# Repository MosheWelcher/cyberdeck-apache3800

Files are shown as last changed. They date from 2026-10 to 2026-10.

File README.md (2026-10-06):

# Apache 3800 Cyberdeck — panels CAD

Parametric OpenSCAD panels for a cyberdeck built into a Harbor Freight
**Apache 3800** case (item 63927).

- **Lid:** screen panel + screen clips + lid brackets (this repo).
- **Base:** keyboard / ports faceplate that screws onto the
  [Apache 3800 Panel Bracket](https://www.printables.com/model/1478000-apache-3800-panel-bracket)
  by JohnS - N0CTL (print that ring separately; its hole pattern is built in here).

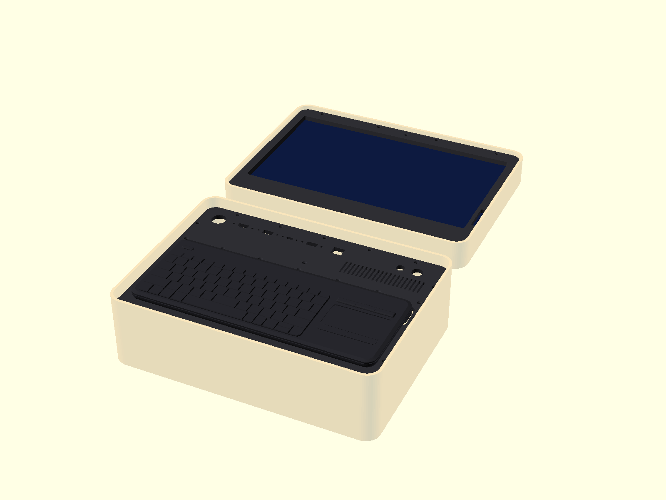
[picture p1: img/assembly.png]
assembly


## Layout

| File | What it is |
|---|---|
| `config.scad` | **Every dimension lives here.** Case, screen preset, ports, keyboard, printer bed, fasteners. |
| `parts/lid_panel.scad` | Screen bezel: window with 45° bevel, retainer bosses on the back, countersunk mount holes. |
| `parts/screen_retainer.scad` | Flat clips that screw onto the bosses and clamp the screen. |
| `parts/lid_bracket.scad` | Posts for the lid floor (insert top + bottom) — lid-side equivalent of the Printables bracket. |
| `parts/base_faceplate.scad` | Keyboard battery-hump slot, port cutouts, vent grille, holes matching the Printables bracket ring. |
| `view_stls.scad` | Imports the exported STLs so you can look at them (F5). |
| `assembly.scad` | Fit-check: case opened flat with both panels. Preview only. |
| `scripts/export.sh` | Renders every part to `stl/` and previews to `img/`. |
| `scripts/step_to_stl.py` | Converts a STEP to STL (gmsh) for previews, e.g. the K400 model. |
| `scripts/step_info.py` | Reads holes / extents / faces out of STEP files (how third-party parts were measured). |
| `docs/DESIGN.md` | Design record: every decision, measurement source, open question. |
| `CLAUDE.md` / `AGENTS.md` | Guide for AI agents (and humans) working on the repo. |
| `ref/` | Notes on reference dimensions. |

Coordinates: origin at the centre of the case opening; **−Y = handle (front)**,
**+Y = hinge (back)**; panel front face is the top (+Z).

## Workflow

1. Edit `config.scad` (screen preset, port list, keyboard size, `bed`).
2. Open `assembly.scad` in OpenSCAD, press **F5** to fit-check.
3. Export STLs from Git Bash in the repo root:
   ```bash
   scripts/export.sh
   ```
   ~10 s with an OpenSCAD **development build** (2024+, Manifold engine); the
   script finds one under `%LOCALAPPDATA%\Programs\OpenSCAD-Nightly` and falls
   back to the 2021.01 release (~35 min). Get builds from
   openscad.org → Downloads → Development Snapshots. Single part:
   `openscad --backend=manifold -D 'piece=[0,1]' -o out.stl parts/lid_panel.scad`.

## Splitting for the printer

The panels are ~380 × 270 mm. If they exceed `bed` (default 256 × 256) they are
cut into tiles with a **half-lap joint**: the back half of one tile overlaps the
front half of its neighbour across a `lap_w` band. Each seam gets M3 countersunk
screws (front) + hex-nut pockets (back) every `seam_hole_pitch` mm — glue the lap
too. Force a layout with e.g. `lid_split_x = [0]; lid_split_y = [];`, or set
both to `[]` for a single piece on a big bed. Tiles export as
`<part>_tile_<i>_<j>.stl`.

## What's measured vs. assumed

**From the Printables bracket STEP (v8):**
- Case interior at bracket height: **380 × 270 mm, R17 corners.**
- 16 M3 insert positions of the 4-piece bracket ring → `base_mount_holes`.
- Bracket height 17 mm.

**From Harbor Freight spec:** inside 383 × 271 mm at the rim, lid depth 44 mm,
base depth 108 mm.

**MEASURE before printing** (tagged in `config.scad`):
- `lid_panel_drop` — how far below the lid rim the screen panel sits (gasket lip).
- `base_panel_drop` — where your brackets end up below the base rim (16 mm default so the lid clears the keyboard).
- Screen preset dimensions — all approximate; caliper your panel + driver board.
- Port type sizes — generic panel-mount extensions vary.

## Screen: portable "travel" monitor

Default `screen = "vilva15.6"`: the **VILVA V156F1** 15.6" FHD monitor
([Amazon B0BTSFVMLV](https://www.amazon.com/dp/B0BTSFVMLV)), 367.8 × 224.8 ×
7.6 mm from the listing — not yet measured. Its ports and buttons are split
over both short ends, with only ~5.5 mm to the lid wall (checked against the
case CAD): use very low-profile right-angle plugs that turn toward the lid
floor. A finger notch in the panel's right end (`lid_notches` in
`config.scad`) lets you reach the power button and brightness wheel — check
which end yours are on and move it if needed. Generic presets `"travel15.6"` / `"travel14"` remain.
`lid_panel.scad` stops with an error if a monitor is too big for the clip /
lid-post layout. A travel monitor is a whole
unit in its own ~9 mm shell, so the panel frames its glass and the clips clamp
the shell edge — no teardown needed. To fit yours, measure and edit its preset:

- outer shell width × height × thickness (`module_w/h/t`)
- visible picture area width × height (`active_w/h`)
- picture-centre offset: travel monitors have a thicker bottom chin, so the
  picture sits **higher** than the shell centre (`active_off_y`, ~+5–10 mm)

Things to plan for: its USB-C / mini-HDMI ports and OSD buttons are on the shell
edges, which end up behind the panel — check that the cable plugs (often
right-angle ones are needed) clear the lid brackets, and set brightness before
mounting.

## Keyboard: Logitech K400 Plus (sits on top)

The K400 sits **flat on top of the faceplate**. Only its battery hump (the
thicker strip along its back edge, ~8 mm deeper than the flat underside)
drops through a **357 × 40.5 mm slot with R6 rounded corners** in the plate
(sized from the real K400 model + 1 mm clearance). The hump in the slot also
locates the keyboard so it can't slide; add a few velcro dots if you want it
held down. Lift it off to use it wirelessly or change batteries.

- The slot sits under the keyboard's back edge (keyboard centred at
  `kb_offset`, hump toward the hinge). 14 of the 16 bracket holes are used — the middle
  hole on each end bracket sits too close to the slot end and is skipped.
- With the keyboard on top it stands ~14 mm above the plate, so the plate is
  set **16 mm below the base rim** (`base_panel_drop`) — that leaves ~8 mm
  between the keys and the lid panel when the case is closed. Mount the
  brackets at that height (or change the value and re-export).
- **See it on the plate:** `assembly.scad` and `view_stls.scad` show the real
  K400 model when `ref/local/k400_plus.stl` exists (kept out of the repo —
  GrabCAD terms). Make it once from the GrabCAD STEP (needs
  `pip install --user gmsh`):
  `python scripts/step_to_stl.py <Downloads>/Logitech_K400_PLUS.stp ref/local/k400_plus.stl`.
  Without it, set `kb_model_stl = ""` in config.scad to see a box stand-in.
- The horizontal print seam sits behind the keyboard (`base_split_y = [44]`);
  ports and vent are in the strip behind it.

Details: `ref/k400-plus.md`.

## License

[MIT](LICENSE) © MosheWelcher — except third-party files in `ref/`, which keep
their own licenses (listed in [`NOTICE`](NOTICE) and below).

## Credits

- **Apache 3800 Panel Bracket** by JohnS - N0CTL —
  [Printables 1478000](https://www.printables.com/model/1478000-apache-3800-panel-bracket),
  [CC BY 4.0](https://creativecommons.org/licenses/by/4.0/). Original STEP included
  unmodified in `ref/`; `base_mount_holes` and the case interior/corner dimensions
  are derived from it. See `ref/printables-bracket.md`.
- **Logitech K400 Plus** model by Tomáš Stroka —
  [GrabCAD](https://grabcad.com/library/logitech-k400-plus-2); keyboard
  outline and underside profile measured from it (file not redistributed).

## Hardware

- Battery charge port: [Adafruit 4218](https://www.adafruit.com/product/4218) USB-C round panel mount (22 mm hole, port row)
- M3 heat-set inserts (M3 × 5.7, 4.0 mm hole)
- M3 countersunk screws: 10 mm (6 mm panels), M3 hex nuts (seams)
- Foam tape for `screen_shim`
- Print: PETG / ABS / ASA-GF, 4 walls, 4 top/bottom, 30–45 % infill.
  Print panels front-face-down for a clean visible side.

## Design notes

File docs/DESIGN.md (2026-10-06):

# Design record — Apache 3800 cyberdeck panels

Everything an agent or collaborator needs to continue the design: what was
decided, why, where every number came from, what is still open. Keep it
current — append to the decision log when you change something.

Coordinates: mm, origin at the centre of the case opening, **−Y = front
(handle)**, **+Y = hinge**, +X = right. Numbers below are for the current
`config.scad` defaults.

---

## 1. Hardware (decided by the owner)

| Item | Choice | Status |
|---|---|---|
| Case | Harbor Freight **Apache 3800** (item 63927) | owned |
| Screen | **VILVA V156F1** 15.6" FHD portable monitor ([amazon.com/dp/B0BTSFVMLV](https://www.amazon.com/dp/B0BTSFVMLV)), USB-C + mini-HDMI | model known (2026-10-05); preset `vilva15.6` from the listing — **not measured yet** |
| Keyboard | **Logitech K400 Plus** (keyboard + touchpad, wireless, 2×AA) | decided; modelled from a STEP |
| Base mounting | **Printables 1478000 "Apache 3800 Panel Bracket"** (4-piece ring, M3 heat-set inserts) | owner has the STEP + a Bambu `.3mf` for it |
| Printer | **Bambu X1C**, 256 × 256 bed | → panels split into 2 × 2 tiles |
| Computer / battery / I/O boards | **not chosen** | don't assume; ask |

## 2. Case

Harbor Freight spec: inside 383 × 271 mm at the rim (15.063" × 10.688"), lid
depth 44 mm (1.75"), base depth 108 mm (4.25"). Front = handle side, hinge at
the back.

**Source ranking (owner, 2026-10-06):** 1. the Printables bracket STEP
(photos show it fitted in real cases) → **380 × 270 mm, R17 corners**
(fillet centres ±173, ±118), used for both halves; 2. the Harbor Freight spec
→ lid depth **44**; 3. a third-party case CAD from the web (`Lid.step`, see
`ref/apache-3800-case.md`, low trust) → only what 1 and 2 don't cover, tagged
`MEASURE`: walls lean in **0.03 mm per mm**, **≈R21 rounded corner** where the
lid walls meet the floor (starts ~28 mm down; 16 mm wide at the floor),
gasket groove in the top of the wall with nothing sticking into the cavity.
It disagrees with 1/2 on corner radius (R20) and lid depth (46.5).

Unmeasured (tagged `MEASURE`): `lid_panel_drop` (how far below the lid rim the
screen panel face sits; the CAD shows no gasket lip inside, so 6 is a free
choice), `base_panel_drop` (where the brackets end up below the base rim).

## 3. Lid — screen panel

Files: `parts/lid_panel.scad`, `parts/screen_retainer.scad`, `parts/lid_bracket.scad`.

- **Panel**: 377.3 × 267.3 mm, R15.6, 6 mm thick (`case_in − 2·(panel_gap +
  lid_draft_inset)`; the draft inset is the wall lean at the panel's back face).
- **Monitor**: VILVA V156F1 (`vilva15.6`). Listing: 14.48 × 8.85 × 0.30" →
  **367.8 × 224.8 × 7.6 mm** (photos say 0.19" = 4.8 mm at the thin edge, so
  7.6 is the thickest point), 1.68–1.88 lb, 1920 × 1080 IPS → standard 15.6"
  active area 344.2 × 193.6. Thin top/side bezels, thick bottom chin: picture
  centre estimated **+10 mm** above the shell centre from product photos.
  **Controls are on both short edges** (manual's "Function Keys & Ports"
  diagram): one edge has mini-HDMI + 2 × USB-C; the other has the 3.5 mm
  jack, OTG USB, the **multi-function wheel** (push up = brightness, press =
  menu), a power LED and the **power button**. Both groups sit in the thick
  chin end; rough diagram reading: wheel ≈ 49 mm, power ≈ 68 mm from the
  bottom edge. Which edge is left/right is not confirmed. (Earlier notes said
  "all on the right" — wrong.)
- **Window**: active area + 0.5 mm/side = **345.2 × 194.6 mm**, centred at
  (0, +10). 45° × 2 mm bevel on the viewing side.
- **Monitor retention**: 8 bosses on the panel back, **all on the long edges**
  (4 per edge at x = ±46, ±137.9, y = ±116.9), height = monitor thickness +
  0.5 mm foam shim, M3 heat-set insert each. 8 flat clips (`screen_retainer`)
  screw on and overlap the monitor shell by 4 mm. No short-edge bosses: the
  368 mm shell leaves only ~4.7 mm per side inside the 377 mm panel. Even count
  keeps x = 0 free for the seam. If the shell is wedge-shaped (4.8 → 7.6 mm),
  the thin-edge clips need extra foam.
- **Mounting**: 8 countersunk M3 holes (`lid_mount_holes`, y = ±127.9) — 4
  per long wall at x = ±50, ±150 — onto **8 printed posts** (`lid_post()` in
  `lib/common.scad`, exported as `lid_bracket`): 18 × 12 × **32 mm** (lid
  depth − drop − panel). The posts **sit on the floor fillet** (their bottom is
  cut to the R21 curve with a 0.3 mm glue gap) with the back face 0.3 mm off
  the wall — they cannot reach the flat floor, the fillet fills the bottom
  16 mm next to the wall. Sized for the 44 mm spec depth: if the lid is
  really 46.5 deep (case CAD), they hang up to 2.5 mm above the fillet and
  the wall screw / glue holds them — so they fit either way. Inserts: top (panel screw) and **back face** (screw
  sideways through the 5.5 mm lid wall), and/or VHB/epoxy on the back. Fit
  order: screw the panel onto the posts, set it in the lid, then fix the posts. The former 4 end-wall posts
  (x = ±184.5, y = ±90) were dropped: they sat under the monitor. Holes avoid
  the seams (x = 0, y = 0) and the bosses.
- **Fit checks** (`lid_panel.scad` asserts — the render stops with a message):
  every boss inside the panel, no boss on a lid post, no lid post under the
  monitor, monitor inside the leaning lid walls (echo `LID monitor-to-wall
  gap`). Current margins: boss edge ↔ post 1.0 mm; monitor end ↔ lid wall
  **5.5 mm**, top/bottom 22 mm. Also checked visually against the
  third-party lid CAD (sections through a post and the monitor end).
- **Finger notch** (owner's choice, 2026-10-06) for the power button and
  brightness wheel: an open slot in the panel's end (`lid_notches`, default
  right end, 35–80 mm up from the monitor's bottom edge = 45 mm long). It
  reaches 3 mm over the monitor bezel (`notch_over`) and runs out through the
  panel edge into the 5.5 mm wall gap, R3 corners; ~6 mm of panel stays beside
  the window bevel. Use a fingertip/nail on the wheel and button. Which end
  and where are **rough** (manual diagram) — measure and move it. An assert
  stops the render if a notch runs past the monitor's end. Panel frame: +y is
  up on the open screen, so "bottom" = −y.
- Both monitor ends sit behind the panel, 5.5 mm from the wall; the cables need **very low-profile right-angle plugs** (5.5 mm is
  less than most right-angle USB-C heads) that turn back toward the lid
  floor (~24 mm free behind the monitor).

Presets in `screen_presets` (all approximate): `7`, `10.1`, `13.3`, `15.6`
(bare panels), `travel15.6`, `travel14` (generic travel monitors),
`vilva15.6` (the owner's, default) and `custom`. Format
`[module_w, module_h, module_t, active_w, active_h, active_off_x, active_off_y]`.

## 4. Base — keyboard / ports faceplate

File: `parts/base_faceplate.scad`.

### 4.1 Plate and the Printables bracket ring

- **Plate**: `base_plate = [378, 268, 16]` → ~1 mm gap to the 380 × 270 R17 walls
  at bracket height, 6 mm thick (bracket tops 22 mm below the rim = drop + thickness).
- **Bracket ring** (from `ref/apache-3800-panel-bracket-v8.step`, see
  `ref/printables-bracket.md`): four bodies — Front (x −120…120, y −135…−123),
  Back (mirror), two L-shaped end pieces wrapping the corners (x ±115…±190).
  17 mm tall; the plate rests on the 12 mm-wide top face (inner faces at
  y = ±123 and x = ±178); a 5 mm strip continues down the wall with
  horizontal Ø4 holes (screws into the case wall).
- **16 insert positions** (`base_mount_holes`): Front/Back y = ∓128 at
  x = −70, 0, 70; ends at (±140, ±128) and (±183, −85 / 0 / 85).
  **14 are used**: `used_mount_holes` auto-skips any hole that would land
  within ~6 mm of the keyboard slot, which drops the two middle end-bracket
  holes (±183, 0) since the slot became full keyboard width.

### 4.2 Keyboard: K400 Plus, sits on top

Measured from the GrabCAD STEP (see `ref/k400-plus.md`):

| Feature | Value |
|---|---|
| Outline at widest shell edge | 355 × 140 mm (spec 354.3 × 139.9 × 23.5) |
| Keys | stand ~2 mm above the frame top |
| Flat underside | 12 mm below frame top — rests on the plate |
| Battery hump | 8 mm below the flat underside (20 below frame top), along the back edge — faces **+Y** (hinge) |
| Hump footprint at the plate top | full width ±177.4 × 38.5 mm from the back edge (front blends in with a large fillet; at the plate underside, 6 mm down: ±174.3 × 30.3). Back corners R≈15 in plan. From cross-sections of the STL |
| Touchpad | right side |

Design (owner's choice: keyboard flat on the plate, minimal hole — keeps the
plate simple, e.g. for a possible future aluminium plate; **don't start
aluminium work until asked**):
- Keyboard centred at `kb_offset = (0, −40)` → occupies y −110…+30.
- **Hump slot** 357 × 40.5 mm (footprint + 1 mm/side), **R6** corners,
  centred (0, 10.75) → y −9.5…31. The hump hangs ~2 mm below the plate
  underside. Fit checked against the real model (keyboard ∩ plate = empty):
  clears up to ~R10 and still clears with the slot 0.5 mm smaller per side
  at R6; R13+ hits the front corners. The slot also
  locates the keyboard; velcro dots optional. Lift off to use wirelessly /
  change batteries.
- **Lid clearance**: keyboard top (keys) stands 14 mm above the plate. With
  `base_panel_drop = 16` the keys are 2 mm below the base rim; the lid panel
  face is 6 mm below the lid rim → **~8 mm** clearance closed. (At the old
  10 mm drop it would have been only 2 mm.) Brackets must be installed so
  the plate top is at that depth.
- The slot leaves ~10.5 mm of plate at each end beside it; the strip behind
  the slot is tied to the back tiles by the y = 44 seam screws.

### 4.3 Ports, vent

`ports` (type, x, y, rot) on a row at **y = 106**: 2× USB-A, USB-C, HDMI, RJ45,
12 mm and 16 mm round (switch / LED / GX16). Sizes in `port_types` are
**generic panel-mount extension guesses** — measure the real parts. One vent
grille `[110, 76, 120, 26]` (2.5 mm slots @ 6 mm) between the seam band and
the port row. Port/vent placement is placeholder until the owner picks
internals.

**Battery charge input**: [Adafruit 4218](https://www.adafruit.com/product/4218)
USB-C round panel-mount extension (`usbc_round`, 22 mm hole = 21.5 min +
0.5 print clearance) at **(−160, 106)** — back-left corner, left end of the
port row. Its nut (~29.5 mm OD) on the back stays ~3 mm clear of the left end
bracket (inner face x = −178), ~2 mm of the back bracket (y = 123), ~8 mm of
the USB-A at −120, and clear of the bracket screws (−140, 128) / (−183, 85);
panel limit 16 mm (plate is 6).
Back side is a 30 cm USB-C cable to the (not yet designed) battery.
Spec in `ref/adafruit-4218.md`.

## 5. Printing: tiles and lap joints

`lib/common.scad` splits any panel larger than `bed − bed_margin` into tiles
(`auto_split` picks the orientation needing fewer tiles; seams can be forced
with `lid_split_x/y`, `base_split_x/y` lists).

- **Half-lap joint**: in a `lap_w` = 20 mm band at each seam, the back half
  (z < t/2) belongs to the left/lower tile and the front half to the
  right/upper tile (`tile_mask` shifts the seam ±lap/2 per layer). Visible
  face shows one clean line.
- **Seam screws**: M3 countersunk from the front + hex-nut pocket on the back,
  spaced ~`seam_hole_pitch` along each seam, always including one
  `seam_edge_inset` from each panel edge, minus any in a keep-out
  (windows, cutouts, mount holes, bosses, the lid monitor's footprint — the
  back-side nut would hold the monitor off the panel). A mount screw
  landing in a lap band clamps it instead.
- Current layout: **lid** 2 × 2, seams x = 0 / y = 0, **2 seam screws**, both
  on x = 0 at y = ±123.5. The y = 0 seam has **none** (window in the middle,
  monitor over both ends) — it is glue-only; each tile is still screwed to its
  own 2 lid posts. **Base** 2 × 2, seams x = 0 / y = 44 (forced
  behind the keyboard), **9 seam screws** (one at (0, −61.5) sits under the
  keyboard — countersunk flush); the bracket screws at (0, ±128) also clamp
  the x = 0 lap. Glue the laps.
- Tiles export as `stl/<part>_tile_<i>_<j>.stl` (i along X, j along Y,
  0 = negative side). Print front-face-down for the best visible surface.

## 6. Hardware list (current design)

- M3 heat-set inserts (Ø4 hole, 5.7 mm): 8 (screen bosses) + 16 (lid posts,
  top + bottom) + 14 for the Printables brackets (2 of its 16 positions unused).
- M3 countersunk screws: 14 base mount, 8 lid mount, 11 seam (9 base + 2
  lid; M3 × 10 mm, seams need nuts); 8 pan/button heads for clips;
  lid-post fixing screws if not glued.
- M3 hex nuts: 11 (seams).
- Velcro dots for the keyboard (optional).
- Foam tape (0.5 mm) for the monitor shim. Glue (e.g. CA/epoxy) for laps.

## 7. Measured vs. assumed

| Value | Source | Confidence |
|---|---|---|
| Case rim interior, depths | Harbor Freight spec | good |
| Interior at bracket height 380 × 270 R17 | bracket STEP | good |
| Bracket insert positions, heights | bracket STEP | good (as designed; real install may vary) |
| K400 outline / underside profile | GrabCAD STEP + Logitech spec | good |
| Monitor shell 367.8 × 224.8 × 7.6 | VILVA Amazon listing (B0BTSFVMLV) | listing only — **measure** |
| Monitor picture offset +10 mm, port side | product photos | **estimated** |
| Port sizes | generic | **assumed** |
| USB-C charge port hole (Adafruit 4218) | Adafruit spec | good (not test-fitted) |
| `lid_panel_drop`, `base_panel_drop` | guesses | **assumed** |
| Lid wall lean 0.03/mm, floor fillet R21 | third-party case CAD (`Lid.step`) | **low** — measure |
| Lid depth 44 | HF spec (case CAD says 46.5) | **assumed** — posts work for both |
| VILVA control layout (two edges, wheel/power positions) | manual diagram | layout good, positions **rough** |

## 8. Open questions / next steps

0. **Finger notch position** — confirm on the real VILVA which end has the
   power button + wheel and how far up from the bottom edge they are; edit
   `lid_notches`. If the notch is too tight for a fingertip, options are a
   wider `notch_over` (thins the strip beside the window) or shifting the
   monitor toward the other end (`screen_offset`), if the port end allows.
1. **Measure the VILVA when it arrives** — shell w × h (listing: 367.8 ×
   224.8), thickness at top and bottom edge (wedge?), picture w × h and its
   distance from the bottom/top shell edge; update `vilva15.6`. If the real
   shell is ≤ ~355 mm wide, end-wall posts and short-edge clips could return.
2. ~~K400 end-bracket clearance~~ — gone: keyboard now sits on top of the plate.
3. **Internals** — computer (e.g. SBC/mini PC), power (battery / power bank:
   owner mentioned a "battery spot" but never specified — ask before designing),
   cable routing between lid and base, hub. Ports/vent positions follow from this.
4. **Measure** `lid_panel_drop`, real port hardware; confirm the brackets can
   be installed with the plate top 16 mm below the rim (`base_panel_drop`).
5. Seam strength — lid now has only 2 seam screws and the y = 0 seam is
   glue-only. Options if it feels weak: flush nut pockets so screws can sit
   under the monitor, or a glued backing strip across the side frames.
6. ~~Repo license~~ — MIT chosen (see decision log).

## 9. Decision log

All 2026-10-05.

- Project scaffolded: OpenSCAD, config-first, lid screen panel + base
  faceplate, 2×2 lap-jointed tiles for a 256 bed.
- Printables bracket STEP parsed → base hole pattern, case R17 / 380 × 270.
  Bracket credited (owner confirmed CC BY 4.0); STEP added to `ref/`.
- Screen → portable travel monitor; `travel15.6` default; short-edge bosses 2
  per side; lid mount holes moved off seams; seam screws gained edge-inset +
  keep-outs.
- Keyboard → K400 Plus, **drop-in flush on hangers** (owner chose over
  "sits on top" and "just a hole"). Opening moved to (0, −40); base seam forced
  to y = 44; ports to y = 106; end-bracket holes beside the opening skipped.
- Plate outline set to 378 × 268 R16 (1 mm wall gap all round).
- Owner asked for bracket "inner-lip" fit checks/gauges, then **asked to remove
  them** — don't re-add.
- OpenSCAD dev build (Manifold) adopted: export ~35 min → ~10 s.
- Repo made **public**; commits use the GitHub noreply email; work lives on
  `main`.
- Licensed **MIT** (© MosheWelcher); third-party bracket STEP excluded
  (CC BY 4.0), listed in `NOTICE`.
- Keyboard mount changed: K400 now **sits flat on top of the plate**; only a
  347 × 35 mm slot for its battery hump. Hangers, the big opening and the
  hole-skipping beside it removed (all 16 bracket holes used again).
  `base_panel_drop` 10 → 16 mm so the closed lid clears the keys (~8 mm).
  Reason: simpler flat plate, possibly aluminium (heat sink) later — owner
  said **not to start aluminium work yet**.
- Panels thickened **4 → 6 mm** (lid + base; owner found 4 mm too thin):
  ~3.4× stiffer, lap halves 3 + 3 mm, lid posts now 32 mm. The base plate top
  stays 16 mm below the rim, so the brackets install 2 mm lower (tops 22 mm
  below the rim) and keyboard height / ~8 mm lid clearance are unchanged.
  Aluminium heat-sink plate discussed: ~3 mm 5052/6061 *if* done later
  (not started).
- Real K400 model added to the previews (`k400_preview()`; STEP → STL with
  gmsh into the ignored `ref/local/`). Visual check: keyboard sits flat on the
  plate, hump in the slot with ~1.4 mm front / ~1 mm rear clearance, ~11.5 mm
  of plate either side. **(Wrong — see next entry.)**
- Hump slot corrected and rounded (owner asked for rounder corners and a
  verified fit). Cross-sections of the real model through the plate showed
  the old 347 × 35 slot did **not** fit: the K400's thick back runs the full
  width (±177.4 at the plate top) and blends forward with a fillet to
  y ≈ −8.5, so the keyboard would have sat on the slot edges. Slot now from
  the model + 1 mm: `kb_hump_size = [355, 38.5]` → 357 × 40.5, R6 (owner
  chose R6 over R10, the largest that clears). Fit checked by intersecting the
  model with the plate (empty, also with 0.5 mm extra margin). Cost: the two
  middle end-bracket holes (±183, 0) are auto-skipped → 14 of 16 used; seam
  screws unchanged (9).
- **USB-C battery charge port** added (owner's pick: Adafruit 4218 round
  panel-mount extension): new port type `usbc_round` (Ø22), placed at
  (80, 106) on the port row. Only the battery *input* — the battery itself
  is still unspecified (ask before designing a bay). Seam screws unchanged.
- USB-C charge port moved to the **back-left corner** (−160, 106) at the
  owner's request ("top left" read as hinge side, left).
- **Monitor chosen: VILVA V156F1** (owner sent amazon.com/dp/B0BTSFVMLV).
  New preset `vilva15.6` = 367.8 × 224.8 × 7.6, picture offset +10 (listing +
  photos; not measured). 11 mm wider than the generic preset, so: clip bosses
  moved to the long edges only (4 + 4), the 4 end-wall lid posts dropped
  (12 → 8), monitor footprint added to the lid seam-screw keep-outs (removes
  the y = 0 seam screws — they would have pressed the nut into the monitor;
  the old 357 mm preset already overlapped by ~4 mm), and fit-check asserts
  added to `lid_panel.scad`.

2026-10-06:

- **Lid checked against the real case CAD** (owner's Apache 3800 FreeCAD/STEP
  model; `ref/apache-3800-case.md`). The monitor fits (5.5 mm per end, 22 mm
  top/bottom), but the old lid panel (381 × 269 R16) was ~1.6 mm too long with
  too-tight corners, and the lid posts ran into the wall and up to ~11 mm into
  the wall-to-floor fillet (and were 2.5 mm short of the real floor). Fixed:
  case numbers from the CAD (380 × 270, R20, depth 46.5, wall lean 0.03/mm,
  fillet R21) → panel 377.3 × 267.3 R18.6; posts 18 × 12 × 34.5, bottom cut to
  the fillet, back insert for a screw through the wall; new monitor-in-lid
  assert. Base geometry unchanged.
- **Source ranking set by the owner**: the Printables bracket STEP (seen
  installed in real cases) outranks the downloaded case CAD ("from random
  joe"). Corner radius back to **R17** (bracket; CAD said R20) → panel
  R15.6; lid depth back to the HF spec **44** (CAD said 46.5) → posts 32 mm,
  still cut for the fillet so they fit a deeper lid too. CAD-only values
  (wall lean, fillet) tagged `MEASURE`.
- **Finger notch** for the monitor's power button + brightness wheel (owner
  chose it over printed button extenders and "no access"): `lid_notches`
  `[[1, 35, 80]]`, 3 mm over the bezel, open into the wall gap. Seam screws
  keep out of it. Position from the manual diagram — measure.
- VILVA manual read: controls are split over both short edges (power +
  wheel on one), not all on the right. They are not reachable once mounted —
  open question 0.

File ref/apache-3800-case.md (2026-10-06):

# Apache 3800 case — CAD measurements

Source: "Apache 3800 Weatherproof Case from Harbor Freight" CAD model
(FreeCAD + STEP: `Lid.step`, `Bottom.step`, `Handle.step`,
`3800 Case Assembly.step`), downloaded by the owner as
`apache-3800-weatherproof-case-from-harbor-freight-1.snapshot.4.zip`
(GrabCAD-style snapshot). **Not committed** — no redistribution rights
checked; the owner keeps the zip in Downloads. Only measurements are used.

**Trust level: low.** Made by an unknown uploader. The owner ranks the
Printables bracket STEP (`printables-bracket.md`, photos of it installed in
real cases) above this model. `config.scad` takes from this file only what
the bracket and the Harbor Freight spec don't cover — lid wall lean and the
wall-to-floor fillet — tagged `MEASURE`. Where they overlap: size agrees
(380 × 270); corner radius R20 here vs **R17 from the bracket → R17 used**;
lid depth 46.5 here vs **44 from the HF spec → 44 used**.

How it was measured (2026-10-06): `Lid.step` meshed with gmsh (lid shell =
volume 7; volume 4 is the gasket, 3/6 the latches, 1/8 hinge bits), then sliced
with planes in a small Python script.

## Lid (CAD frame = deck frame: rim top z = 0, opening up, origin = centre)

| Feature | Value |
|---|---|
| Inside at the rim (z −1) | x ±189.97, y ±134.97 → **379.9 × 269.9** |
| Inside at z −12 (panel back) | 379.4 × 269.4 |
| Inside at z −20 (monitor back) | 379.0 × 269.0 |
| Inside at z −28 | 378.4 × 268.4 → wall lean ≈ **0.03 mm per mm** |
| Inside corner radius (plan) | **R20** (fit error < 0.03 mm) |
| Inside floor | **z −46.5** (outside skin −52, feet/ribs to −54.8) |
| Wall-to-floor fillet | ≈ **R21**; wall is 1 mm in at z −32, 5.7 at −40, 10.7 at −44, 16 at −46 |
| Gasket groove | in the top of the wall, x 193.8…201.4 / y 138.8…146.4, 8 deep — outside the cavity, no lip into it |
| Wall thickness (z −20) | 5.5 mm |
| Interior features | none (no bosses or ribs inside the cavity) |

Harbor Freight's spec says 383 × 271, lid 1.75" (44.5).

Not yet checked against this model: the base (`Bottom.step`) — the base plate
is sized from the Printables bracket STEP (380 × 270 R17 at bracket height).

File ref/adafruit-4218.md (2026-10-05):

# Adafruit 4218 — USB C Round Panel Mount Extension Cable

Source: <https://www.adafruit.com/product/4218> (spec as listed, 2026-10-05).

| Spec | Value |
|---|---|
| Panel hole | 21.5 mm min, up to ~27 mm |
| Overall diameter incl. nut | ~29.5 mm |
| Max panel thickness | 16 mm |
| Back side | 30 cm cable, USB-C plug |
| Retention | plastic nut; front lip hides the hole |

Used as `port_types` → `usbc_round` (22 mm hole) in `config.scad`, placed on
the base port row at (−160, 106) (back-left corner) as the battery charging input.
Not measured yet — check the real part.

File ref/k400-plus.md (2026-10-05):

# Logitech K400 Plus — extracted data

Sources:
- Logitech spec: 354.3 × 139.9 × 23.5 mm, 390 g.
- GrabCAD model **"LOGITECH K400 PLUS"** by Tomáš Stroka (2018),
  https://grabcad.com/library/logitech-k400-plus-2 (`Logitech_K400_PLUS.stp`).
  Not redistributed here (GrabCAD terms) — download it from GrabCAD.

Measured from the STEP vertices (model axes: X width, Y thickness, Z depth):

| Feature | Value |
|---|---|
| Outline at widest shell edge | 355 × 140 mm |
| Shell edge band (full width) | 2–7 mm below the frame top |
| Frame top → key tops | keys stand ~2 mm proud |
| Frame top → flat underside | 12 mm (front ~105 mm of depth) |
| Battery hump (rear) | 20 mm below frame top, ±168.5 mm wide, rear ~26 mm |
| Touchpad | right side, ~X 83…165 |

Hump footprint through the plate (used for the plate slot) — from horizontal
cross-sections of the STL (`ref/local/k400_plus.stl`) placed on the plate,
depth measured below the flat underside:

| Depth | Width | Front edge, from the back edge |
|---|---|---|
| 0.1 mm | ±177.4 (full width) | 38.3 mm |
| 0.5 mm | ±177.4 | 36.0 mm |
| 3 mm | ±176.6 | 32.3 mm |
| 5.9 mm | ±174.3 | 30.3 mm |

The thick back runs the full width and blends into the underside with a
large fillet; its back corners are R≈15 in plan. (An earlier reading from
the STEP vertices, ±172.5 × 33 mm, was too small; the slot built on it did
not fit.) Config: `kb_hump_size = [355, 38.5]`.

The keyboard sits on top of the base plate; only the hump passes through
(`kb_hump_size`, `kb_slot_clear` in config.scad).

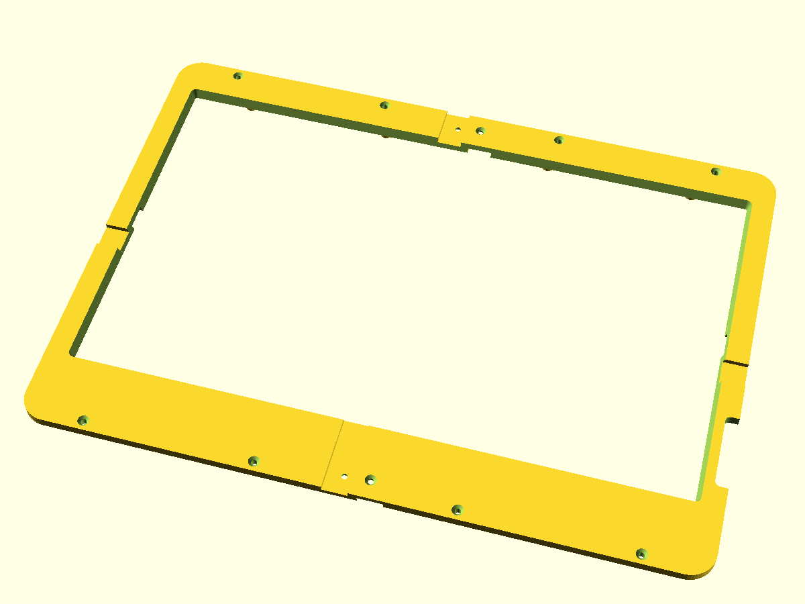
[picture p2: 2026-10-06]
img/lid_panel_tiles.png

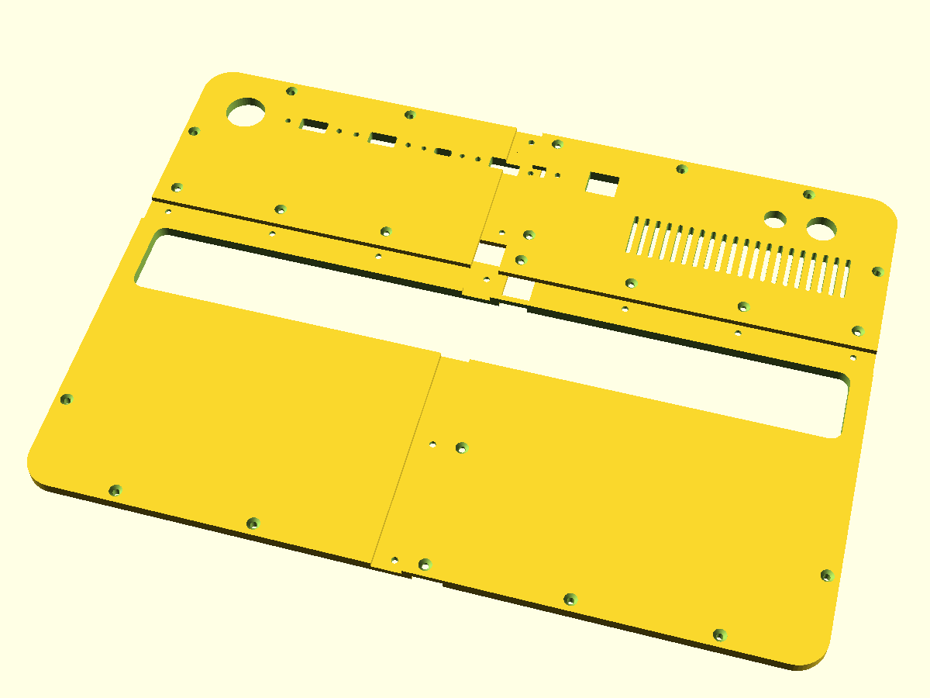
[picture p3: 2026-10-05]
img/base_faceplate_tiles.png

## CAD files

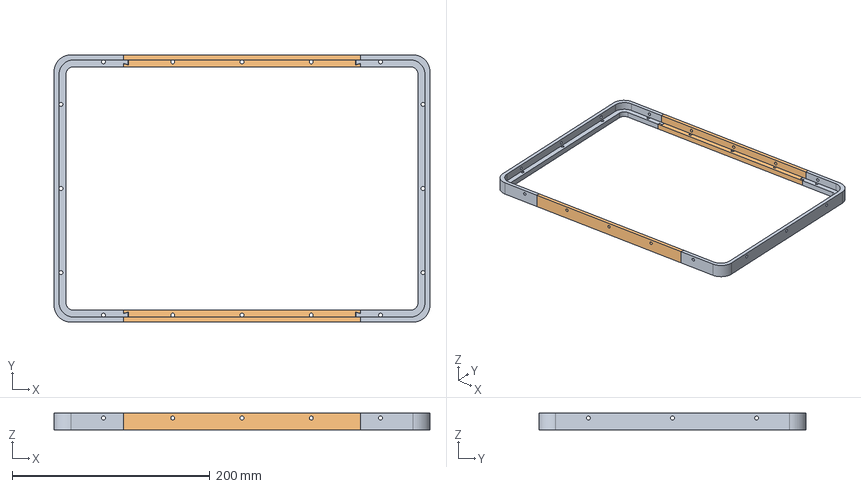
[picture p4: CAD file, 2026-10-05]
ref/apache-3800-panel-bracket-v8.step
380.0 x 270.0 x 17.0 mm
Left Bracket
Front Bracket
Back Bracket
Right Bracket

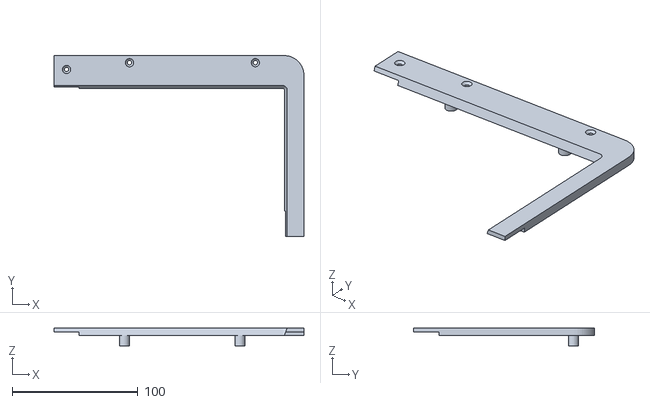
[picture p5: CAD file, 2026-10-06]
stl/lid_panel_tile_1_1.stl
198.6 x 143.6 x 14.1

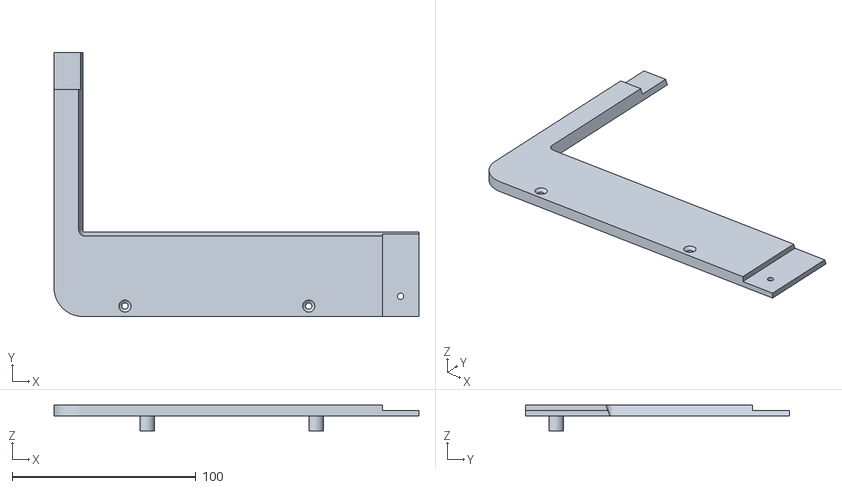
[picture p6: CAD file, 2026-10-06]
stl/lid_panel_tile_0_0.stl
198.6 x 143.6 x 14.1

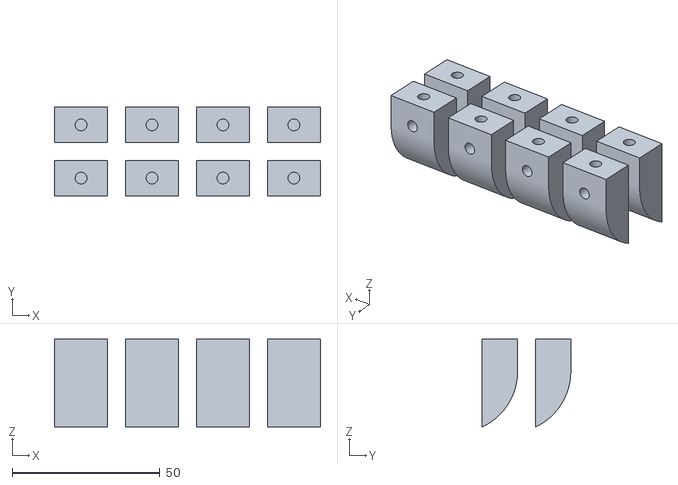
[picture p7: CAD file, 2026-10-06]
stl/lid_bracket.stl
90.0 x 30.0 x 29.8

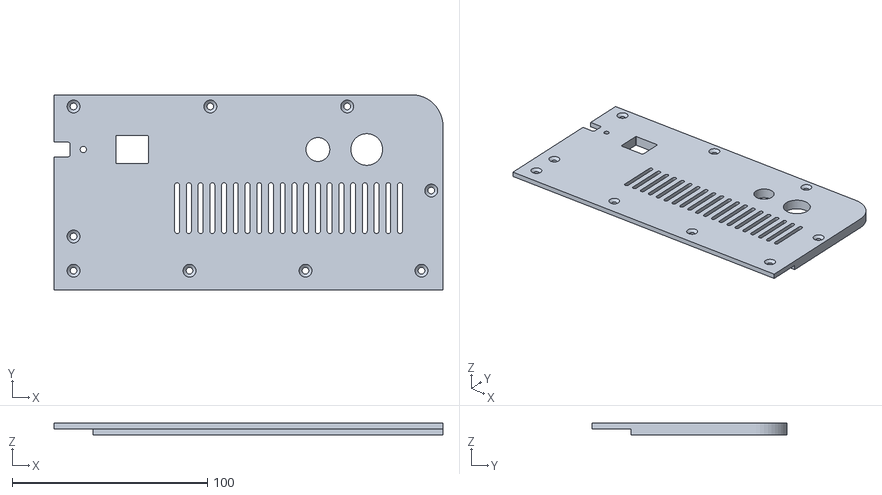
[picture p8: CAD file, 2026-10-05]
stl/base_faceplate_tile_1_1.stl
199.0 x 100.0 x 6.00

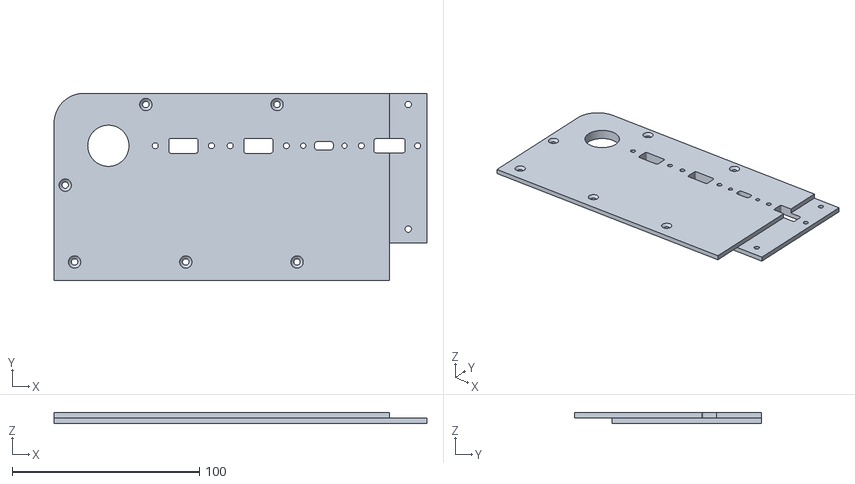
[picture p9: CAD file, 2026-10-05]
stl/base_faceplate_tile_0_1.stl
199.0 x 100.0 x 6.00

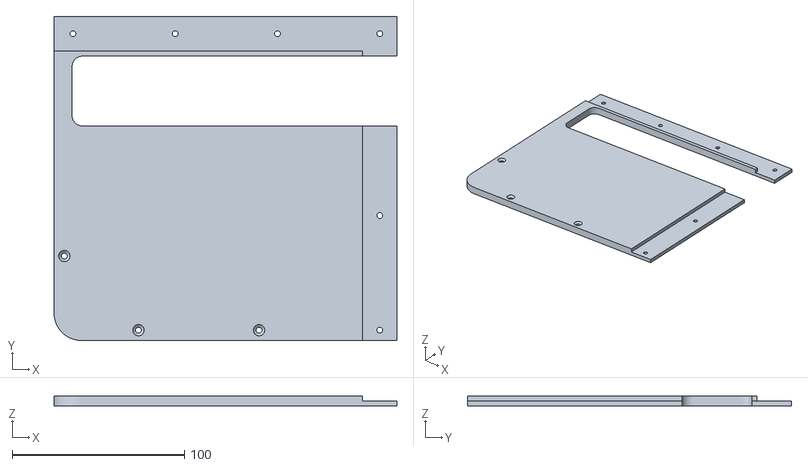
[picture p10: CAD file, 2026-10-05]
stl/base_faceplate_tile_0_0.stl
199.0 x 188.0 x 6.00

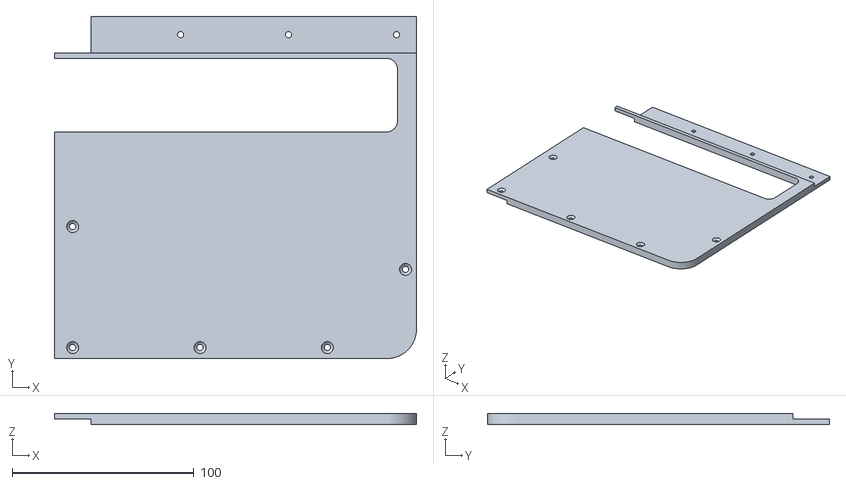
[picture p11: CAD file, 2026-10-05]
stl/base_faceplate_tile_1_0.stl
199.0 x 188.0 x 6.00

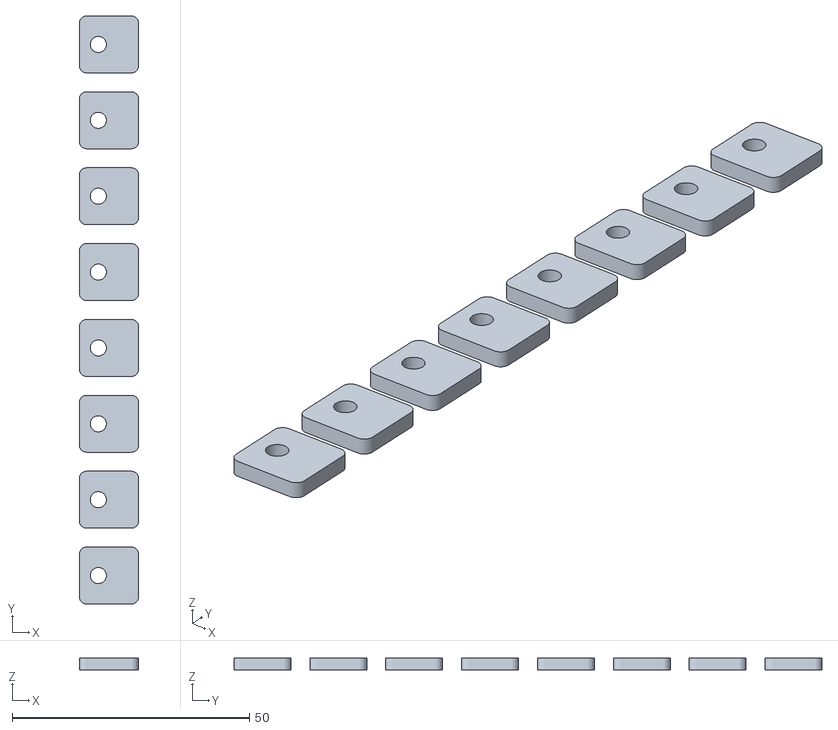
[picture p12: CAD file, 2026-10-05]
stl/screen_retainer.stl
12.5 x 124.0 x 2.50

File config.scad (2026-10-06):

// =====================================================================
//  Apache 3800 Cyberdeck — single source of truth for every dimension.
//  Edit values HERE, never inside parts/*.scad.
//  Values tagged MEASURE are best-known defaults: verify with calipers /
//  radius gauges against YOUR case and parts before printing.
//  Units: millimetres. Origin: centre of the case opening, at the rim.
// =====================================================================

$fn = 48;

// ---------------------------------------------------------------------
//  Case (Harbor Freight Apache 3800, item 63927)
// ---------------------------------------------------------------------
// Source ranking: (1) the Printables bracket STEP (ref/, photos show it
// fitted in real cases), (2) the Harbor Freight spec, (3) a third-party case
// CAD from the web (ref/apache-3800-case.md) — used only where (1) and (2) say
// nothing, and tagged MEASURE.
case_in_l     = 380;   // inside length (bracket STEP 380; case CAD 379.9 at the rim; HF spec 383)
case_in_w     = 270;   // inside width  (bracket STEP 270; case CAD 269.9; HF spec 271)
lid_depth     = 44;    // MEASURE lid rim -> inside floor (HF spec 1.75"; case CAD says 46.5 -> lid posts
                       // would then sit up to 2.5 mm above the floor fillet, held by their wall screw)
base_depth    = 108;   // inside base depth    (spec 4.25")
case_corner_r = 17;    // inside corner radius (bracket STEP R17; case CAD says R20 for the lid)
lid_wall_draft = 0.03; // MEASURE lid walls lean inward this much per mm of depth (case CAD only)
lid_fillet_r  = 21;    // MEASURE rounded wall-to-floor corner inside the lid (case CAD only)
panel_gap     = 1.0;   // clearance per side, panel edge -> case wall

// ---------------------------------------------------------------------
//  Printer — panels larger than this are split into lap-jointed tiles
// ---------------------------------------------------------------------
bed             = [256, 256]; // usable bed X, Y
bed_margin      = 12;         // keep-out per axis (includes lap overlap)
lap_w           = 20;         // width of the lap-joint band at each seam
seam_hole_pitch = 60;         // target spacing of M3 screws along each seam
seam_edge_inset = 11;         // outermost seam screw, from the panel edge

// ---------------------------------------------------------------------
//  Fasteners (M3 throughout)
// ---------------------------------------------------------------------
m3_clear_d      = 3.4;
m3_csk_d        = 6.6;   // 90-degree countersink head diameter
m3_insert_d     = 4.0;   // heat-set insert hole (M3 x 5.7 typical)
m3_insert_depth = 6;
m3_nut_af       = 5.5;   // hex nut across flats (seam joints)

// ---------------------------------------------------------------------
//  Panels (shared)
// ---------------------------------------------------------------------
panel_t = 6;   // faceplate thickness (lid + base); front/back halves (3 + 3) form the lap joint

// ---------------------------------------------------------------------
//  LID — screen panel
// ---------------------------------------------------------------------
lid_panel_drop  = 6;    // MEASURE front face of panel below lid rim (clear gasket lip)
lid_draft_inset = lid_wall_draft * (lid_panel_drop + panel_t);   // panel shrink per side: wall lean at the panel back face
lid_split_x = "auto";   // "auto" or list of seam X positions, e.g. [0] or []
lid_split_y = "auto";   // "auto" or list of seam Y positions

// Screen choice: one of the preset names below.
screen = "vilva15.6";
// [module_w, module_h, module_t, active_w, active_h, active_off_x, active_off_y]
// active_off = active-area centre relative to module centre, viewed from front.
// ALL PRESETS ARE APPROXIMATE — measure your panel; driver boards vary.
screen_presets = [
  ["7",      [164.9, 100.0, 5.7, 154.2,  85.9, 0, 0]],   // 1024x600 HDMI kit class
  ["10.1",   [235.0, 143.0, 4.5, 217.0, 135.6, 0, 0]],   // 1280x800 IPS class
  ["13.3",   [300.0, 187.0, 3.5, 293.8, 165.2, 0, 3]],   // 1920x1080 eDP class
  ["15.6",   [359.5, 223.8, 3.2, 344.2, 193.6, 0, 5]],   // NV156FHM class
  // Portable "travel" monitors (whole unit in its own shell, thicker bottom chin
  // pushes the active area up). Typical 15.6" / 14" USB-C units — MEASURE yours.
  ["travel15.6", [357.0, 223.0, 9.0, 344.2, 193.6, 0, 8]],
  ["travel14",   [318.0, 200.0, 9.0, 309.4, 173.9, 0, 7]],
  // Owner's monitor: VILVA V156F1 15.6" FHD (amazon.com/dp/B0BTSFVMLV).
  // Shell 14.48 x 8.85 x 0.30" from the listing (photos say 0.19" at the thin
  // edge; 7.6 is the thickest point). Active area = standard 15.6" FHD.
  // Thin top/side bezels, thick bottom chin -> picture ~10 mm above centre
  // (estimated from product photos). Controls on BOTH short edges (manual):
  // mini-HDMI + 2x USB-C on one; 3.5 mm, OTG, wheel, LED, power on the other.
  // MEASURE all of it when it arrives.
  ["vilva15.6",  [367.8, 224.8, 7.6, 344.2, 193.6, 0, 10]],
  ["custom", [200.0, 120.0, 4.0, 190.0, 110.0, 0, 0]]
];
screen_offset     = [0, 0];  // module centre relative to panel centre
window_margin     = 0.5;     // window larger than active area, per side
window_chamfer    = 2.0;     // 45-degree bevel on the viewing side
screen_shim       = 0.5;     // foam/tape between glass and panel back
// Retainer bosses + clips that clamp the screen to the panel back
boss_d            = 8;
bosses_long_side  = 4;       // per top/bottom edge (even count keeps x=0 free for the seam)
bosses_short_side = 0;       // per left/right edge; 0 = none (a 368 mm monitor leaves no room at the ends)
clip_w            = 12;
clip_t            = 2.5;
clip_overlap      = 4;       // how far each clip reaches over the screen edge
// Finger notches: open slots in the panel's short ends so a fingertip/nail
// reaches the monitor's edge controls (VILVA: brightness wheel + power button
// sit in the ~5.5 mm gap between monitor end and lid wall). Each entry:
//   [end, from, to]  end = 1 right / -1 left (seen from the front);
//   from/to = span along the monitor edge, mm up from its bottom (chin) edge.
// MEASURE: which end has the controls and where (manual diagram, rough:
// wheel ~49 mm, power ~68 mm up). [] = no notches.
lid_notches   = [[1, 35, 80]];
notch_over    = 3;     // notch reaches this far over the monitor bezel (keeps ~6 mm of panel beside the window bevel)
notch_r       = 3;     // notch corner radius

// Lid brackets: stand on the lid floor, carry M3 inserts for the panel.
lid_bracket_size = [18, 12];   // footprint [along wall, away from wall] (12 keeps 1 mm to the clip bosses)
lid_post_gap     = 0.3;        // post back face / bottom -> lid wall and floor fillet (glue gap)
// Posts hug the long walls and sit on the floor fillet (they can't reach the
// flat floor: the fillet fills ~16 mm next to the wall). Hole centre from the
// rim-level wall line = wall lean down to the fillet + gap + half the post.
lid_post_inset = lid_wall_draft * (lid_depth - lid_fillet_r) + lid_post_gap + lid_bracket_size[1] / 2;
lid_mount_holes = [
  [-150,  case_in_w/2 - lid_post_inset], [-50,  case_in_w/2 - lid_post_inset], [50,  case_in_w/2 - lid_post_inset], [150,  case_in_w/2 - lid_post_inset],
  [-150, -case_in_w/2 + lid_post_inset], [-50, -case_in_w/2 + lid_post_inset], [50, -case_in_w/2 + lid_post_inset], [150, -case_in_w/2 + lid_post_inset]
];

// ---------------------------------------------------------------------
//  BASE — keyboard / ports faceplate on the Printables brackets
//  (printables.com/model/1478000 — M3 inserts in the bracket top edge)
// ---------------------------------------------------------------------
base_panel_drop  = 16;   // MEASURE faceplate top below base rim (keyboard on top stands 14 mm; lid panel is 6 mm below its rim -> ~8 mm clearance closed)
base_plate = [378, 268, 16];   // faceplate outline [x, y, corner_r]: ~1 mm to the wall at bracket height
base_split_x = "auto";
base_split_y = [44];     // behind the keyboard opening (auto would cut through it)
// M3 insert positions of the 4-piece Printables bracket ring, from the case
// centre. Derived from "Apache 3800 Panel Bracket" by JohnS - N0CTL, CC BY 4.0
// (ref/apache-3800-panel-bracket-v8.step). Bracket is 17 mm tall.
// Front = -Y (handle side), Back = +Y (hinge side).
base_mount_holes = [
  [-70, -128], [0, -128], [70, -128],                    // Front Bracket
  [-70,  128], [0,  128], [70,  128],                    // Back Bracket
  [ 140, -128], [ 140, 128], [ 183, -85], [ 183, 0], [ 183, 85],   // +X end bracket
  [-140, -128], [-140, 128], [-183, -85], [-183, 0], [-183, 85]    // -X end bracket
];
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

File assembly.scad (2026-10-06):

// Fit-check preview: case opened flat (lid behind the hinge, +Y),
// both panels in place. Open in OpenSCAD and press F5. Not for printing.
include <lib/common.scad>
use <parts/lid_panel.scad>
use <parts/lid_bracket.scad>
use <parts/base_faceplate.scad>

hinge_gap = 40;   // visual spacing between base and opened lid

module cavity(depth) {
    color(c_case) difference() {
        translate([0, 0, -depth]) plate(case_in_l + 8, case_in_w + 8, case_corner_r + 4, depth);
        translate([0, 0, -depth + 3]) plate(case_in_l, case_in_w, case_corner_r, depth);
    }
}

// Base half
cavity(base_depth);
translate([0, 0, -base_panel_drop]) {
    color(c_panel) translate([0, 0, -panel_t]) base_faceplate_whole();
    k400_preview();   // real K400 model if ref/local/k400_plus.stl exists (see config.scad)
}

// Lid, opened 180 degrees about the hinge: interior faces up
translate([0, case_in_w + hinge_gap, 0]) {
    cavity(lid_depth);
    translate([0, 0, -lid_panel_drop - panel_t]) {
        color(c_panel)  lid_panel_whole();
        color(c_screen) screen_dummy();
    }
    // posts at the hole positions, back face to the nearest wall
    color("gray") for (p = lid_mount_holes)
        translate([p[0], p[1], -lid_depth]) rotate(lid_post_rot(p)) lid_post();
}

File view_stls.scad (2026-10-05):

// Viewer for the exported STLs in stl/ (run scripts/export.sh first).
include <lib/common.scad>   // keyboard position + preview model
// Open in OpenSCAD and press F5. Tiles import at their real positions,
// so they reassemble into whole panels; set explode > 0 to pull them apart.

explode   = 0;        // mm gap between tiles (try 15)
lid_tiles  = [2, 2];  // [nx, ny] — match the stl/lid_panel_tile_*.stl files
base_tiles = [2, 2];  // [nx, ny] — match the stl/base_faceplate_tile_*.stl files
show_lid      = true;
show_base     = true;
show_brackets = true;
show_clips    = true;
show_keyboard = true;   // K400 sitting on the base plate

module tiles(part, n) {
    for (i = [0 : n[0] - 1], j = [0 : n[1] - 1])
        translate([(i - (n[0] - 1) / 2) * explode, (j - (n[1] - 1) / 2) * explode, 0])
            color(((i + j) % 2 == 0) ? [0.25, 0.25, 0.3] : [0.35, 0.35, 0.42])
                import(str("stl/", part, "_tile_", i, "_", j, ".stl"));
}

// Base faceplate in front, lid screen panel behind it (as if the case lay open)
if (show_base) tiles("base_faceplate", base_tiles);
if (show_keyboard) translate([0, 0, panel_t]) k400_preview();   // on the plate top
if (show_lid)  translate([0, 300, 0]) tiles("lid_panel", lid_tiles);

// Small parts off to the right
if (show_brackets) color("orange")    translate([230, -60, 0])  import("stl/lid_bracket.stl");
if (show_clips)    color("lightblue") translate([230, 120, 0])  import("stl/screen_retainer.stl");

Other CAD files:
stl/lid_panel_tile_0_1.stl
stl/lid_panel_tile_1_0.stl
parts/base_faceplate.scad
parts/lid_bracket.scad
parts/lid_panel.scad
parts/screen_retainer.scad

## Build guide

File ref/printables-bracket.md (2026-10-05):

# Printables Apache 3800 Panel Bracket — extracted data

**"Apache 3800 Panel Bracket"** by **JohnS - N0CTL** (@jrsphoto),
https://www.printables.com/model/1478000-apache-3800-panel-bracket —
licensed **CC BY 4.0** (https://creativecommons.org/licenses/by/4.0/).

`apache-3800-panel-bracket-v8.step` in this folder is the author's original
STEP (Fusion export, 2025-11-11), included unmodified. The base faceplate's
mounting-hole pattern and the case interior dimensions in `config.scad` are
derived from it.

Assembly of four bodies: Left Bracket, Front Bracket, Back Bracket, Right Bracket
(Right = Left rotated 180° about Y).

| Feature | Value |
|---|---|
| Inner wall fillet | R17, centres at (±173, ±118) → interior 380 × 270 |
| Bracket height | 17 mm |
| Top insert holes (Ø4, panel) | Front y=−128 & Back y=+128 at x=−70, 0, 70; ends at (±140, ±128) and (±183, −85/0/85) |
| Wall screw holes (Ø4, horizontal) | z=12 from bracket bottom, into the case wall |

Author notes: M3 heat-set inserts in the top edge; printed in GF-ABS, 4 top/bottom
layers, 45 % infill.

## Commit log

2026-10-05 Parametric Apache 3800 cyberdeck panels (lid screen panel, base faceplate, brackets, clips)
    Base faceplate hole pattern taken from the Printables 1478000 bracket STEP.
    Panels auto-split into half-lap tiles for the configured printer bed.
    [assembly.scad, base_faceplate.scad, base_faceplate_tile_0_0.stl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]
2026-10-05 Travel-monitor screen presets, seam screws with keep-outs, STL viewer, bracket CC BY 4.0 credit
    - screen default travel15.6 (+ travel14) presets
    - seam screws always placed near panel edges, skipped inside cutouts/mounts
    - view_stls.scad imports exported STLs for viewing
    - include original Printables bracket STEP with attribution
    [apache-3800-panel-bracket-v8.step, base_faceplate.scad, base_faceplate_tile_0_0.stl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]
2026-10-05 K400 Plus drop-in keyboard, bracket-derived plate outline, fit checks, Manifold export
    - base faceplate: 357x142 K400 opening, 8 ledge hangers (parts/kb_hanger.scad),
    bracket holes beside the opening skipped automatically, seam moved behind keyboard
    - plate outline derived from the Printables bracket ring (lib/bracket_ring.scad)
    - parts/fit_test.scad: FIT OK/WARNING checks + printable corner fit gauges
    - export.sh prefers an OpenSCAD dev build with --backend=manifold (~10 s vs ~35 min)
    [assembly.scad, base_faceplate.scad, base_faceplate_tile_0_0.stl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]
2026-10-05 Remove bracket inner-lip fit checks and gauges
    Plate outline kept (378 x 268 R16) as base_plate in config.scad.
    [assembly.scad, base_faceplate.scad, config.scad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]
2026-10-05 Agent/maintainer docs: CLAUDE.md, AGENTS.md, docs/DESIGN.md, STEP measuring tool
    CLAUDE.md: owner preferences, repo map, conventions, commands, verification,
    git/licensing rules, known pitfalls. docs/DESIGN.md: every decision with its
    reason and measurement source, current numbers, open questions, decision log.
    scripts/step_info.py: dumps holes/extents/planes from STEP files.
2026-10-05 Add MIT license (third-party bracket STEP excluded, CC BY 4.0)
2026-10-05 K400 sits flat on top of the base plate; slot only for its battery hump
    - replace the 357x142 drop-in opening with a 347x35 hump slot (also locates the keyboard)
    - remove keyboard hangers (part, STL, plate bolt holes, config) and the
    bracket-hole skipping beside the opening: all 16 bracket holes used
    - base_panel_drop 10 -> 16 mm so the closed lid clears the keys (~8 mm)
    - docs updated (README, CLAUDE.md, docs/DESIGN.md, ref/k400-plus.md)
    [assembly.scad, base_faceplate.scad, base_faceplate_tile_0_0.stl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]
2026-10-05 Panels 4 -> 6 mm thick (lid and base)
    Lid posts follow (32 mm); base plate top stays 16 mm below rim, so the
    brackets install 2 mm lower and keyboard/lid clearance is unchanged.
    [base_faceplate_tile_0_0.stl, base_faceplate_tile_0_1.stl, base_faceplate_tile_1_0.stl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]
2026-10-05 Show the real K400 model on the base plate in the previews
    - scripts/step_to_stl.py: STEP -> STL via gmsh
    - k400_preview(): imports ref/local/k400_plus.stl (git-ignored, GrabCAD terms)
    positioned on the plate top; box stand-in when kb_model_stl is empty
    - assembly.scad and view_stls.scad use it (view_stls: show_keyboard)
    [assembly.scad, config.scad, view_stls.scad]
2026-10-05 Battery-hump slot: size from the real K400 model, R6 corners
    Cross-sections of the K400 model showed the old 347 x 35 slot did not fit:
    the thick back runs the full keyboard width and blends forward with a
    fillet. Slot is now 357 x 40.5 (model + 1 mm/side) with R6 corners; fit
    checked by intersecting the model with the plate. The two middle
    end-bracket holes (+-183, 0) are auto-skipped (14 of 16 used).
    [base_faceplate.scad, base_faceplate_tile_0_0.stl, base_faceplate_tile_0_1.stl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]
2026-10-05 Add USB-C battery charge port (Adafruit 4218)
    New round port type usbc_round (22 mm hole) on the base port row at
    (80, 106). Spec noted in ref/adafruit-4218.md; docs updated.
    [base_faceplate_tile_0_1.stl, base_faceplate_tile_1_1.stl, config.scad]
2026-10-05 Move USB-C charge port to the back-left corner (-160, 106)
    [base_faceplate_tile_0_1.stl, base_faceplate_tile_1_1.stl, config.scad]
2026-10-05 Fit the lid to the owner's monitor: VILVA V156F1 15.6"
    New preset vilva15.6 (367.8 x 224.8 x 7.6, picture +10 mm) from the Amazon
    listing B0BTSFVMLV, now the default. The shell is 11 mm wider than the
    generic preset, so clip bosses move to the long edges only (4 + 4), the four
    end-wall lid posts are dropped (12 -> 8), the monitor footprint joins the lid
    seam-screw keep-outs, and lid_panel.scad asserts that bosses fit the panel
    and no lid post sits under the monitor or on a boss.
    [config.scad, lid_bracket.stl, lid_panel.scad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]
2026-10-06 Fit the lid to the real case CAD: smaller panel, posts on the floor fillet
    Measured the lid from the owner's Apache 3800 CAD model (Lid.step):
    inside 380 x 270 R20, 46.5 deep, walls lean 0.03 mm/mm, R21 wall-to-floor
    fillet. The monitor fits (5.5 mm per end), but the old 381 x 269 panel was
    too long and the lid posts hit the wall and the fillet. Panel is now
    377.3 x 267.3 R18.6; posts are 18 x 12 x 34.5, sit on the fillet and take
    a screw through the wall. New monitor-in-lid assert. Docs: VILVA controls
    are on both short edges and not reachable once mounted (open question).
    [assembly.scad, config.scad, lid_bracket.scad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]
2026-10-06 Rank the Printables bracket above the downloaded case CAD
    Owner: the bracket STEP (photos of it installed in real cases) is the
    better source of truth. Corner radius back to R17 (bracket; CAD said R20)
    -> lid panel R15.6. Lid depth back to the Harbor Freight 44 mm (CAD said
    46.5) -> posts 32 mm, still cut for the floor fillet so they also fit a
    deeper lid. CAD-only values (wall lean, fillet) tagged MEASURE; source
    ranking recorded in config, DESIGN.md, CLAUDE.md and the ref note.
    [config.scad, lid_bracket.stl, lid_panel_tile_0_0.stl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]
2026-10-06 Lid panel: finger notch for the monitor's power button + brightness wheel
    Open slot in the panel's right end (lid_notches [[1, 35, 80]] = 35-80 mm
    up from the monitor's bottom edge), 3 mm over the bezel and out into the
    5.5 mm wall gap, R3 corners; seam screws keep out. Position from the VILVA
    manual diagram, to be measured. Assert if a notch runs past the monitor.
    [config.scad, lid_panel.scad, lid_panel_tile_0_0.stl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]
2026-10-30 Docs: owner has no 3D printer (remove Bambu X1C claim)
    Parts will be ordered from a print service. bed = [256, 256] is now
    described as a tile-size limit; geometry unchanged.
2026-10-30 Base plate: flat aluminium sheet + Cricut mock-up SVG; archive printed faceplate
    - New parts/base_plate_metal.scad (2D): one 378 x 268 sheet of 1/8" 5052,
    plain M3 clearance holes. Exports cut/base_plate.dxf for a cutting
    service and cut/base_plate.svg (mm, 1:1) for a Cricut test-fit.
    - Cutout shapes moved to lib/common.scad (base_cutouts_2d,
    used_mount_holes) so both plates share them; geometry unchanged.
    - Printed tiled faceplate (.scad, STLs, preview) moved to
    archive/base_faceplate/ (still renders, no longer exported).
    - assembly/view_stls show the aluminium plate; docs updated.
2026-10-30 README: show the base plate as SVG, link the cut files
    Export writes img/base_plate.svg (grey-filled copy of cut/base_plate.svg,
    readable on light and dark GitHub themes); replaces img/base_plate.png.
2026-10-30 Cut files: clean R12 DXF (mm) + STEP for the aluminium base plate
    SendCutSend could not quote OpenSCAD's DXF (R10 header with LWPOLYLINE
    entities and no units - likely read as 378 x 268 inches). New
    scripts/cut_files.py, run by export.sh, rewrites the outlines point for
    point as a plain R12 DXF with closed POLYLINEs and $INSUNITS = mm, and
    extrudes them to base_metal_t as cut/base_plate.step (gmsh). Verified:
    strict ezdxf read with 0 audit errors, 52 closed outlines, 378 x 268 mm;
    STEP is one solid with volume = area x 3.175.
2026-10-30 Design log: SendCutSend for the base plate, raw finish (no paint)
2026-10-30 Design record: computers (Pi 2B, Zero 2 W, Pico W) and 4x21700 battery
2026-10-30 Zero 2 W SDR node plan + SMA antenna hole in the base plate
    Record the owner's plan for the Zero 2 W as the deck's dedicated SDR node
    (RTL-SDR Blog V4, GPIO UART link to the Pi 2B, rtl_tcp over Wi-Fi, Pico W
    gpio-shutdown) with review notes: one dongle runs one decoder at a time,
    power budget ~0.7-0.8 A, Wi-Fi under the aluminium plate. Add a 6.5 mm SMA
    bulkhead hole (placeholder at (90, 106)) and regenerate the cut files.
2026-10-30 Deck height in inches: plate top 5/8", bracket tops 3/4" below the rim
    base_panel_drop_in (inches) in config.scad, converted to mm for the models;
    base_plate_metal.scad echoes the mounting heights in inches. 16 -> 15.875 mm,
    cut files unchanged.
